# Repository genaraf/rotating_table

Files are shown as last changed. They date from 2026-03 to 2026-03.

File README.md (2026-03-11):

b# Rotating Table (ESP-IDF, M5Stamp-C3)

Проект управления вращающимся столом с наклоном:
- шаговый двигатель 28BYJ-48 через ULN2003
- серво для наклона (PWM)
- кнопка на `GPIO10`: короткое нажатие `Power`, удержание > 5 сек `Reset`
- Web UI для настроек Wi-Fi, движения и профилей

## Реализовано
- Wi-Fi:
  - `STA + fallback AP` (если STA не поднялся, включается AP)
  - `AP only`
- Web UI:
  - вкладка `Control`: профиль, угол поворота, угол наклона, `Start/Stop`, `Reset(Home 0/0)`
  - вкладка `Profiles`: параметры и профили `create / copy / delete / activate`
  - вкладка `Wi-Fi`: режим AP/STA и SSID/пароли
  - вкладка `About`: имя, версия, `Reset settings` с подтверждением
- Сохранение настроек в NVS

Параметры по умолчанию:
- `min_angle = -45`
- `max_angle = 45`
- стартовый угол при загрузке: `0`
- `turn_grad = 10` означает: 1 оборот стола изменяет наклон на 10 градусов

## Структура модулей
- `main/main.c` — оркестрация запуска
- `main/app_state.c` — состояние, профили, load/save NVS
- `main/motor_control.c` — шаговик + серво + motion task
- `main/button_control.c` — обработка кнопок
- `main/wifi_manager.c` — STA/AP/fallback
- `main/web_server.c` — Web UI и REST API
- `main/board_config.h` — пины и калибровка моторов

## Пины и калибровка (пункт 3)
Все аппаратные параметры вынесены в `main/board_config.h`:
- GPIO пины для ULN2003, серво и кнопок
- `STEPPER_STEPS_PER_REV`
- `STEPPER_DIR` (`1` или `-1`)
- `SERVO_MIN_US`, `SERVO_MAX_US`, `SERVO_PERIOD_HZ`
- пределы наклона `TILT_MIN_DEG_LIMIT`, `TILT_MAX_DEG_LIMIT`

Текущая дефолтная карта:
- `IN1=GPIO4`, `IN2=GPIO5`, `IN3=GPIO6`, `IN4=GPIO7`
- `SERVO_PWM=GPIO8`
- `BTN_POWER=GPIO10`, `BTN_RESET=GPIO10` (одна кнопка: short/long press)

Если у вас другая разводка, меняйте только `board_config.h`.

## Схема подключения
PNG версия: `docs/wiring-diagram.png`

```text
M5Stamp-C3                     ULN2003 board                 28BYJ-48
-----------                    -------------                 --------
GPIO4  ----------------------> IN1
GPIO5  ----------------------> IN2
GPIO6  ----------------------> IN3
GPIO7  ----------------------> IN4
GND    ----------------------> GND -------------------------> GND
5V ext ----------------------> VCC -------------------------> +5V motor
                                                     (5-pin cable from ULN2003 to motor)

M5Stamp-C3                     Servo (tilt)
-----------                    ------------
GPIO8  ----------------------> PWM/SIG
GND    ----------------------> GND
5V ext ----------------------> +5V

Button (active-low, shared actions):
GPIO10 ---[button]---------- GND
short press -> power ON/OFF
hold >5 sec -> factory reset

Power:
- M5Stamp-C3: from USB/5V as usual
- ULN2003 + stepper: external 5V
- Servo: external 5V (желательно отдельная линия)
- All grounds must be common: M5 GND = ULN2003 GND = Servo GND = PSU GND
```

Генератор PNG: `tools/generate_wiring_png.py`

## Сборка и прошивка
```bash
idf.py set-target esp32c3
idf.py build
idf.py -p /dev/ttyUSB0 flash monitor
```

## Web UI
- STA режим: откройте IP устройства в локальной сети
- AP режим: подключитесь к `RTable-Setup` (пароль `12345678`) и откройте `http://192.168.4.1/`

## Подключение питания
- ULN2003 + 28BYJ-48: 5V
- Серво: отдельный 5V источник (желательно)
- Обязателен общий GND между M5Stamp-C3, ULN2003 и серво

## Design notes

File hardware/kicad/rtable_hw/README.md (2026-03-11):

щл# rtable_hw (KiCad)

Files:
- `rtable_hw.kicad_pro` - KiCad project file
- `rtable_hw.kicad_sch` - full wiring schematic with symbols and nets

Open:
1. Start KiCad
2. Open `rtable_hw.kicad_pro`
3. Open schematic editor and load `rtable_hw.kicad_sch`

Implemented schematic blocks:
- `J1` M5Stamp-C3 header
- `U1` ULN2003A
- `J2` 28BYJ-48 motor connector
- `J3` Servo connector
- `J4` Button connector
- `J5` +5V input connector

Implemented net mapping:
- GPIO4/5/6/7 -> ULN2003 IN1/IN2/IN3/IN4
- ULN2003 O1/O2/O3/O4 -> motor coils `COIL_A/B/C/D`
- ULN2003 `COM` -> `+5V`, ULN2003 `GND` -> `GND`
- GPIO8 -> Servo signal
- GPIO10 -> Button (active-low)
- External 5V for ULN2003 + Servo
- Common GND across all blocks

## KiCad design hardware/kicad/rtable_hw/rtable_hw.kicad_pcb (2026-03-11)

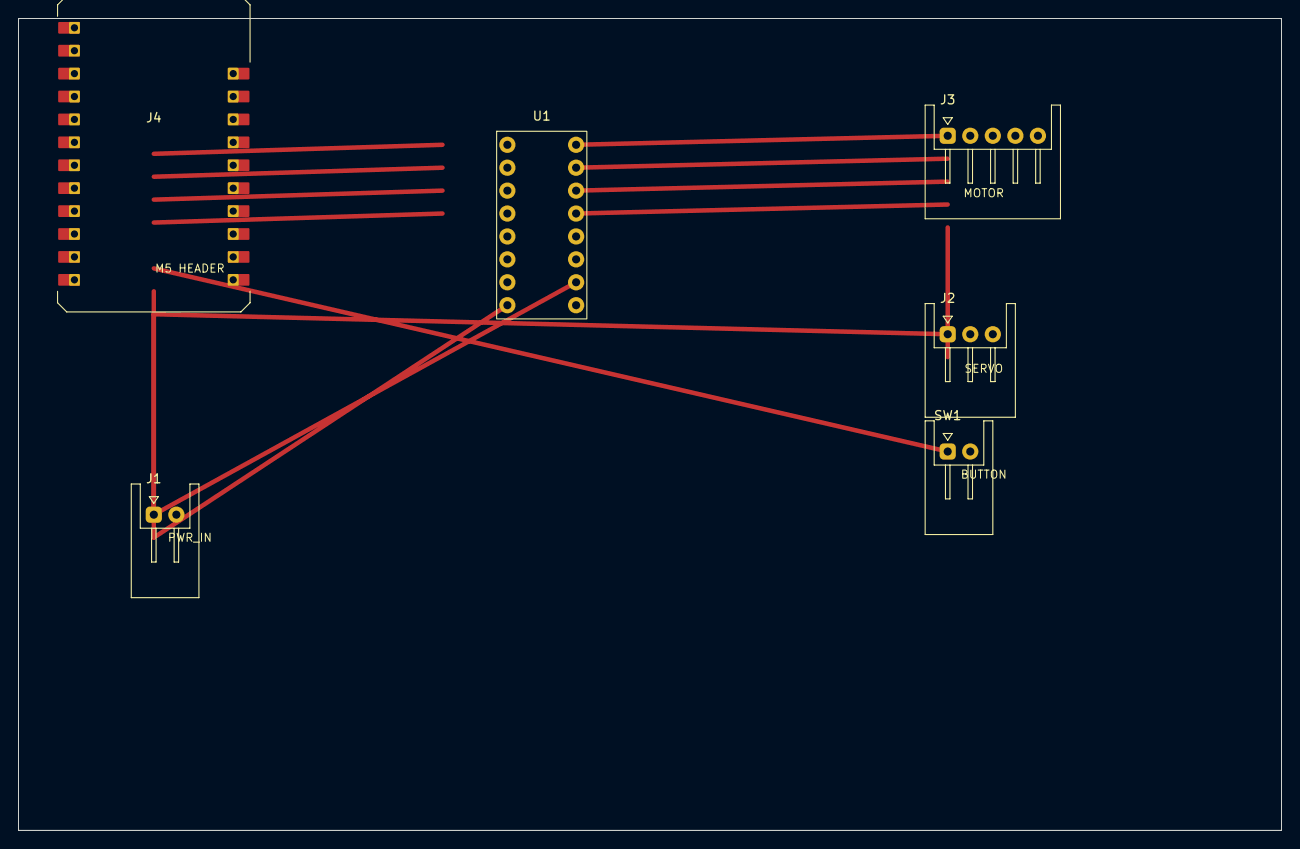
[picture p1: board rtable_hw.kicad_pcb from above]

Board: 2 copper layers, 140.0 x 90.0 mm, 6 parts (0 on the bottom side), 12 nets.

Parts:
J1: PWR_IN; S02B-XASS-1
J2: SERVO; S03B-XASK-1
J3: MOTOR; S05B-XASK-1
J4: M5 HEADER; M5STAMP-C3C3U
SW1: BUTTON; S02B-XASS-1
U1: ULN2003A; ULN2003_DIP16

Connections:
+5V: J1.1, J2.2, J3.5, J4.8, U1.9
COIL_A: J3.1, U1.16
COIL_B: J3.2, U1.15
COIL_C: J3.3, U1.14
COIL_D: J3.4, U1.13
GND: J1.2, J2.3, J4.7, SW1.2, U1.8
GPIO4: J4.1, U1.1
GPIO5: J4.2, U1.2
GPIO6: J4.3, U1.3
GPIO7: J4.4, U1.4
GPIO8: J2.1, J4.5
GPIO10: J4.6, SW1.1

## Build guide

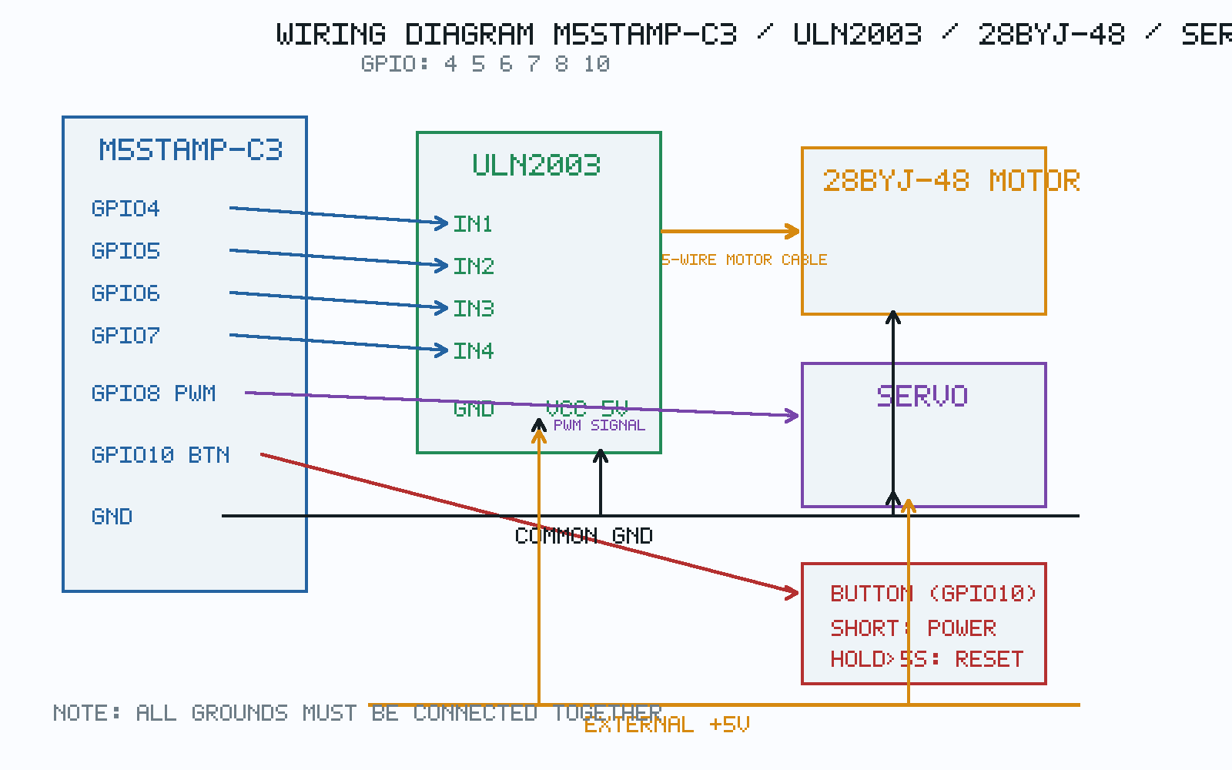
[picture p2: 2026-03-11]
docs/wiring-diagram.png

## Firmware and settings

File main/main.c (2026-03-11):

#include "esp_err.h"
#include "nvs_flash.h"
#include "esp_log.h"

#include "app_state.h"
#include "motor_control.h"
#include "button_control.h"
#include "wifi_manager.h"
#include "web_server.h"

static const char *TAG = "rtable";

void app_main(void) {
    esp_err_t err = nvs_flash_init();
    if (err == ESP_ERR_NVS_NO_FREE_PAGES || err == ESP_ERR_NVS_NEW_VERSION_FOUND) {
        ESP_ERROR_CHECK(nvs_flash_erase());
        err = nvs_flash_init();
    }
    ESP_ERROR_CHECK(err);

    cfg_load();
    g_current_angle = 0.0f;
    if (g_current_angle < g_cfg.min_angle) g_current_angle = g_cfg.min_angle;
    if (g_current_angle > g_cfg.max_angle) g_current_angle = g_cfg.max_angle;

    motor_control_init();
    button_control_init();

    wifi_manager_start();
    web_server_start();

    motor_control_start_task();
    button_control_start_task();

    ESP_LOGI(TAG, "RTable started");
}

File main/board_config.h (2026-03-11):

#pragma once

#include "driver/gpio.h"

// ---------------- Pins (adjust to your exact wiring) ----------------
#define PIN_STEPPER_IN1 GPIO_NUM_4
#define PIN_STEPPER_IN2 GPIO_NUM_5
#define PIN_STEPPER_IN3 GPIO_NUM_6
#define PIN_STEPPER_IN4 GPIO_NUM_7

#define PIN_SERVO_PWM   GPIO_NUM_8

// Buttons are active-low, connected to GND (internal pull-up is enabled).
// With this pin set both actions are on one button:
// short press -> power toggle, hold >5s -> factory reset.
#define PIN_BTN_POWER   GPIO_NUM_10
#define PIN_BTN_RESET   GPIO_NUM_10

// ---------------- Motion calibration ----------------
#define STEPPER_STEPS_PER_REV 4096.0f
#define STEPPER_DIR           1

#define SERVO_PERIOD_HZ 50
#define SERVO_MIN_US    500
#define SERVO_MAX_US    2500

// UI/runtime clamp range for tilt in degrees
#define TILT_MIN_DEG_LIMIT -45.0f
#define TILT_MAX_DEG_LIMIT 45.0f

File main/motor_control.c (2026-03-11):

#include <stdint.h>
#include <math.h>

#include "freertos/FreeRTOS.h"
#include "freertos/task.h"

#include "driver/gpio.h"
#include "driver/ledc.h"
#include "esp_err.h"

#include "board_config.h"
#include "app_state.h"
#include "motor_control.h"

#define HOME_RPM            2.0f
#define HOME_TILT_SPEED_DPS 30.0f

static float s_step_phase = 0.0f;
static int s_step_idx = 0;
static int s_tilt_dir = 1;
static int32_t s_total_steps = 0;

static const uint8_t s_stepper_seq[8][4] = {
    {1, 0, 0, 0},
    {1, 1, 0, 0},
    {0, 1, 0, 0},
    {0, 1, 1, 0},
    {0, 0, 1, 0},
    {0, 0, 1, 1},
    {0, 0, 0, 1},
    {1, 0, 0, 1},
};

static void update_table_angle(void) {
    float a = ((float)s_total_steps * 360.0f) / STEPPER_STEPS_PER_REV;
    a = fmodf(a, 360.0f);
    if (a < 0.0f) a += 360.0f;
    g_table_angle_deg = a;
}

static void stepper_write_phase(int idx) {
    gpio_set_level(PIN_STEPPER_IN1, s_stepper_seq[idx][0]);
    gpio_set_level(PIN_STEPPER_IN2, s_stepper_seq[idx][1]);
    gpio_set_level(PIN_STEPPER_IN3, s_stepper_seq[idx][2]);
    gpio_set_level(PIN_STEPPER_IN4, s_stepper_seq[idx][3]);
}

static void stepper_release(void) {
    gpio_set_level(PIN_STEPPER_IN1, 0);
    gpio_set_level(PIN_STEPPER_IN2, 0);
    gpio_set_level(PIN_STEPPER_IN3, 0);
    gpio_set_level(PIN_STEPPER_IN4, 0);
}

static void servo_setup(void) {
    ledc_timer_config_t t = {
        .speed_mode = LEDC_LOW_SPEED_MODE,
        .duty_resolution = LEDC_TIMER_14_BIT,
        .timer_num = LEDC_TIMER_0,
        .freq_hz = SERVO_PERIOD_HZ,
        .clk_cfg = LEDC_AUTO_CLK,
    };
    ESP_ERROR_CHECK(ledc_timer_config(&t));

    ledc_channel_config_t c = {
        .gpio_num = PIN_SERVO_PWM,
        .speed_mode = LEDC_LOW_SPEED_MODE,
        .channel = LEDC_CHANNEL_0,
        .intr_type = LEDC_INTR_DISABLE,
        .timer_sel = LEDC_TIMER_0,
        .duty = 0,
        .hpoint = 0,
    };
    ESP_ERROR_CHECK(ledc_channel_config(&c));
}

static void servo_set_angle(float angle_deg) {
    float span = g_cfg.max_angle - g_cfg.min_angle;
    float t = span > 0.0f ? (angle_deg - g_cfg.min_angle) / span : 0.0f;
    if (t < 0.0f) t = 0.0f;
    if (t > 1.0f) t = 1.0f;

    float pulse_us = SERVO_MIN_US + t * (SERVO_MAX_US - SERVO_MIN_US);
    uint32_t max_duty = (1u << 14) - 1;
    uint32_t duty = (uint32_t)((pulse_us * SERVO_PERIOD_HZ * max_duty) / 1000000.0f);

    ledc_set_duty(LEDC_LOW_SPEED_MODE, LEDC_CHANNEL_0, duty);
    ledc_update_duty(LEDC_LOW_SPEED_MODE, LEDC_CHANNEL_0);
}

static void run_home_step(float dt_s) {
    float steps_per_sec = (HOME_RPM * STEPPER_STEPS_PER_REV) / 60.0f;
    s_step_phase += steps_per_sec * dt_s;

    while (s_step_phase >= 1.0f) {
        s_step_phase -= 1.0f;

        if (s_total_steps == 0) {
            break;
        }

        int dir = (s_total_steps > 0) ? -1 : 1;
        s_step_idx = (s_step_idx + (dir > 0 ? 1 : 7)) & 0x7;
        stepper_write_phase(s_step_idx);
        s_total_steps += dir;
    }

    update_table_angle();

    float d = -g_current_angle;
    float max_step = HOME_TILT_SPEED_DPS * dt_s;
    if (d > max_step) d = max_step;
    if (d < -max_step) d = -max_step;
    g_current_angle += d;
    servo_set_angle(g_current_angle);

    if (s_total_steps == 0 && fabsf(g_current_angle) < 0.2f) {
        g_current_angle = 0.0f;
        g_table_angle_deg = 0.0f;
        servo_set_angle(g_current_angle);
        g_home_requested = false;
        g_cfg.power_on = false;
        cfg_save();
    }
}

static void run_normal_step(float dt_s) {
    float steps_per_sec = (g_cfg.rpm * STEPPER_STEPS_PER_REV) / 60.0f;
    s_step_phase += steps_per_sec * dt_s;
    int stepped = 0;

    while (s_step_phase >= 1.0f) {
        s_step_phase -= 1.0f;
        int cfg_dir = (g_cfg.rotation_dir >= 0) ? 1 : -1;
        int dir = (STEPPER_DIR > 0 ? 1 : -1) * cfg_dir;
        s_step_idx = (s_step_idx + (dir > 0 ? 1 : 7)) & 0x7;
        stepper_write_phase(s_step_idx);
        s_total_steps += dir;
        stepped++;
    }

    if (stepped > 0) {
        float rev_delta = (float)stepped / STEPPER_STEPS_PER_REV;
        float angle_delta = rev_delta * g_cfg.turn_grad * (float)s_tilt_dir;
        g_current_angle += angle_delta;

        if (g_current_angle >= g_cfg.max_angle) {
            g_current_angle = g_cfg.max_angle;
            s_tilt_dir = -1;
        } else if (g_current_angle <= g_cfg.min_angle) {
            g_current_angle = g_cfg.min_angle;
            s_tilt_dir = 1;
        }

        servo_set_angle(g_current_angle);
    }

    update_table_angle();
}

static void motion_task(void *arg) {
    const TickType_t dt_ticks = pdMS_TO_TICKS(20);
    const float dt_s = 0.02f;

    while (1) {
        if (g_home_requested) {
            run_home_step(dt_s);
        } else if (g_cfg.power_on) {
            run_normal_step(dt_s);
        } else {
            stepper_release();
        }

        vTaskDelay(dt_ticks);
    }
}

void motor_control_init(void) {
    gpio_config_t out_cfg = {
        .mode = GPIO_MODE_OUTPUT,
        .pin_bit_mask = (1ULL << PIN_STEPPER_IN1) | (1ULL << PIN_STEPPER_IN2) |
                        (1ULL << PIN_STEPPER_IN3) | (1ULL << PIN_STEPPER_IN4),
    };
    ESP_ERROR_CHECK(gpio_config(&out_cfg));

    g_current_angle = 0.0f;
    if (g_current_angle < g_cfg.min_angle) g_current_angle = g_cfg.min_angle;
    if (g_current_angle > g_cfg.max_angle) g_current_angle = g_cfg.max_angle;
    g_table_angle_deg = 0.0f;

    servo_setup();
    servo_set_angle(g_current_angle);
}

void motor_control_start_task(void) {
    xTaskCreate(motion_task, "motion_task", 4096, NULL, 8, NULL);
}

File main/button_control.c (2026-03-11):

#include "freertos/FreeRTOS.h"
#include "freertos/task.h"

#include "driver/gpio.h"
#include "esp_err.h"
#include "esp_log.h"
#include "nvs_flash.h"
#include "esp_system.h"

#include "board_config.h"
#include "app_state.h"
#include "button_control.h"

static const char *TAG = "button";

static void button_task(void *arg) {
#if PIN_BTN_POWER == PIN_BTN_RESET
    int hold_ms = 0;
    int prev = 1;
    bool reset_done = false;

    while (1) {
        int p = gpio_get_level(PIN_BTN_POWER);
        if (p == 0) {
            hold_ms += 50;
            if (!reset_done && hold_ms > 5000) {
                reset_done = true;
                ESP_LOGW(TAG, "Factory reset by long press");
                nvs_flash_erase();
                esp_restart();
            }
        } else {
            if (prev == 0 && hold_ms > 50 && hold_ms <= 5000 && !reset_done) {
                g_cfg.power_on = !g_cfg.power_on;
                cfg_save();
                ESP_LOGI(TAG, "Power toggled: %d", g_cfg.power_on);
            }
            hold_ms = 0;
            reset_done = false;
        }

        prev = p;
        vTaskDelay(pdMS_TO_TICKS(50));
    }
#else
    int reset_hold_ms = 0;
    int prev_power = 1;
    int prev_reset = 1;

    while (1) {
        int p = gpio_get_level(PIN_BTN_POWER);
        int r = gpio_get_level(PIN_BTN_RESET);

        if (prev_power == 1 && p == 0) {
            g_cfg.power_on = !g_cfg.power_on;
            cfg_save();
            ESP_LOGI(TAG, "Power toggled: %d", g_cfg.power_on);
        }

        if (r == 0) {
            reset_hold_ms += 50;
            if (reset_hold_ms > 5000) {
                ESP_LOGW(TAG, "Factory reset by button hold");
                nvs_flash_erase();
                esp_restart();
            }
        } else {
            if (prev_reset == 0 && reset_hold_ms > 100) {
                ESP_LOGI(TAG, "Reset button short press ignored");
            }
            reset_hold_ms = 0;
        }

        prev_power = p;
        prev_reset = r;
        vTaskDelay(pdMS_TO_TICKS(50));
    }
#endif
}

void button_control_init(void) {
    gpio_config_t in_cfg = {
        .mode = GPIO_MODE_INPUT,
        .pull_up_en = GPIO_PULLUP_ENABLE,
        .pin_bit_mask = (1ULL << PIN_BTN_POWER) | (1ULL << PIN_BTN_RESET),
    };
    ESP_ERROR_CHECK(gpio_config(&in_cfg));
}

void button_control_start_task(void) {
    xTaskCreate(button_task, "button_task", 3072, NULL, 6, NULL);
}
